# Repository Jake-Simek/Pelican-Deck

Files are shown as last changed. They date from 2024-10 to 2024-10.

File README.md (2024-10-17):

# Overview

This project is my first attempt at building a portable cyberdeck using a Raspberry Pi 4 and a Pelican 1150 case. It’s designed to be fully self-contained, with water-resistant ports, onboard battery power, and cooling fans. My main focus was to create a sleek, functional system for running various scripts and tasks, such as BadUSB attacks, while keeping everything compact and portable.
In the future, I plan to add assembly instructions to the wiki and more wiring diagrams and schematics.

Cyberdeck Build

---

## Features
- **7-inch display**: Built-in for portable use
- **Running Kali Linux**: Ideal for cybersecurity tasks
- **Active cooling system**: 1x 30mm fan and 2x 18mm fans provide airflow when the case is open
- **3 USB ports**: 2 internal, 1 external for peripherals
- **SD card reader**: Built-in for easy storage access
- **HDMI output**: External port for connecting to a larger display
- **USB-C charging**: Convenient power supply for both the Pi and the screen
- **Cat5 Ethernet port**: External network connection for wired access
- **Audio jack**: For headphones or external audio
- **Status LEDs**:
  - Charging indicator
  - Raspberry Pi on/off
  - Screen on/off
  - 3 additional customizable LEDs
- **Switch for screen power**: Automatically turns the screen off when the case is closed
- **Keyboard**: Integrated for ease of use
- **Storage compartments**: Holds SD cards and USB drives under the keyboard
- **Fully-contained battery**: Powers both the Raspberry Pi and screen for portable operation
- **Water-resistant design**: Sealed and protected when closed

---

## Known Issues
- **Overheating**: Cannot operate with the lid closed for extended periods due to heat buildup
- **No trackpad**: There's no way to control the cursor in the OS without an external mouse
- **Boot issue**: Raspberry Pi won’t boot from the SD card reader
- **Status LEDs**: The LEDs are too bright (can be fixed by using different resistors)
- **Charging inconvenience**: The keyboard has to be removed to access the charging port
- **Internal cable management**: Very poor, leading to a cluttered interior
- **Waterproofing**: The build does not maintain the Pelican case’s original waterproof rating
- **Glue used for assembly**: Insert/faceplate is fastened using glue, which could be improved
- **Charging limitations**: Only supports standard USB charging, not USB-C PD; USB-C port is not bi-directional (input only)

---

## Future Goals
- **Custom 18650 battery pack**: Build a battery pack to fit the case better, provide a longer runtime, and support USB-C PD input and output
- **Inductive charging**: Incorporate some form of wireless charging just because 
- **Slightly bigger case**: Upgrade to a larger case for better component fit and expansion
- **New cooling design**: Implement a thermoelectric cooling system to allow operation with the lid closed
- **Add a trackpad**: Include a built-in trackpad for easier navigation
- **Improved waterproofing**: Make the unit fully submersible when closed and water resistant when open 
- **Upgrade to Raspberry Pi 5**: Consider switching to a Raspberry Pi 5 for improved performance
- **Use fasteners instead of glue**: Replace glued components with screw fasteners for a cleaner, more durable assembly
- **Use SSD for booting**: Switch to an SSD for faster and more reliable booting
- **Design custom PCB**: Create a custom PCB for improved wire management and cleaner internal layout
- **More improvements to come**: This project is evolving, and additional upgrades are planned for future versions

---

## Parts List

#### Disclaimer
Some of the links may have changed, so the parts may not be *identical*. Everything looks the same on the listings, but these parts were all ordered over a year ago.

---

#### Case and External I/O

- **Pelican Case**: [Pelican 1150 Case](https://shorturl.at/xyr0k) or [alternative link](https://www.pelican.com/us/en/product/cases/protector/1150/)
- **Water-resistant Panel Mount I/O (sold by [Power Signal Data Connector Store](https://www.aliexpress.com/store/1102188024) on AliExpress)**:
  - [External HDMI Port](https://shorturl.at/CyrGC) or [alternative link](https://www.aliexpress.us/item/3256804676511038.html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)
  - [External USB Port](https://shorturl.at/Cf8bj) or [alternative link](https://www.aliexpress.us/item/3256805021108099.html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)
  - [External USB-C Port](https://shorturl.at/6hTVx) or [alternative link](https://www.aliexpress.us/item/3256804676644038.html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)
  - [External RJ45 Port](https://shorturl.at/9zwq1) or [alternative link](https://www.aliexpress.us/item/3256805248603359.html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)

  These can be ordered in any color and configuration, but I ordered mine in black with metal nuts. All connectors are ports, but soldering versions are available.

---

#### Display and Input

- **Display**: [7-inch 1024x600 HDMI Display](https://shorturl.at/NZxAf) or [alternative link](https://www.aliexpress.us/item/3256806868466798.html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)
- **Keyboard**: [7-inch Tablet Keyboard](https://a.co/d/doeQoq1) or [alternative link](https://www.amazon.com/dp/B088ZWT5N1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)
 – You can also find versions with a trackpad, but the keyboard base may need modification.
- - **3.5mm Audio Jack**: [Panel Mount 3.5mm Audio Jack (3-pin)](https://shorturl.at/4XXrT) or [alternative link](https://www.aliexpress.us/item/3256805998541350.html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)

---

#### Cooling and Switches

- **Fans**:
  - [30mm Fan (5V)](https://shorturl.at/P3yWi) or [alternative link](https://www.aliexpress.us/item/3256806120222119.html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)
  - [20mm Fan (5V Hydraulic Bearing)](https://a.co/d/7ztwXzH) or [alternative link](https://www.amazon.com/dp/B08MKVSKR6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)
- **Rocker Switches**: [Small Round 2-pin Rocker Switches](https://shorturl.at/hRt7r) or [alternative link](https://www.aliexpress.us/item/3256807356199141.html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)
- **Lid Switch**: [Refrigerator Door Light Switch (Normally Closed)](https://a.co/d/ivMNV4H) or [alternative link](https://shorturl.at/g9zLX)

---

#### Internal Components

- **Internal USB Ports**: [USB to USB 3.0 Dual Panel Mount](https://a.co/d/hqzMyTw) or [alternative link](https://www.amazon.com/dp/B09QQJJML1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)
- **SD Card Extender**: [Micro SD to SD Card Extender](https://shorturl.at/vaQC8) or [alternative link](https://www.aliexpress.us/item/3256803938544773.html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)
  > Note: For some reason, the Pi won't boot from an SD card plugged into this. I'm currently using it with a USB to Micro-USB adapter for reading SD cards, but it works intermittently. You may want to find an alternative.
- **Brass Standoffs**: [Brass Standoffs](https://shorturl.at/BhvH3) or [alternative link](https://www.aliexpress.us/item/2251832748907515.html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) – Any small standoff that fits the Pi’s holes should work fine. I inserted mine into the 3D printed part using a soldering iron. 

---

#### LEDs and Power

- **LEDs and Resistors**:
  - [5mm LEDs](https://shorturl.at/MhEKz) or [alternative link](https://www.aliexpress.us/item/3256805522196114.html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) – Any standard 5mm LED will work; mine were pulled from a DIY Pi kit. 
  - [390 Ohm Resistors](https://shorturl.at/njeu3) or [alternative link](https://www.aliexpress.us/item/3256804747550699.html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) – Used for the LEDs. You may want to use a higher resistance as these are quite bright. 
- **Diode**: [3A Diode (supports 5V)](https://a.co/d/aqU21aW) or [alternative link](https://www.amazon.com/dp/B0D4QNTT4V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)
 – This is used to prevent the charging LED from being powered by the battery bank, so it only turns on during charging. This setup prevents the USB-C port from being used as a power source, as noted in the issues section. 
---

#### Cables and Wiring

- **Cables**:
  - [Micro HDMI to HDMI](https://shorturl.at/lDclC) or [alternative link](https://www.aliexpress.us/item/3256802014452724.html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)
  - [Micro HDMI to Mini HDMI](https://a.co/d/1WwkHYU) or [alternative link](https://www.amazon.com/dp/B08BFZFT7R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)
  - [USB A to USB A](https://shorturl.at/Ay4hM) or [alternative link](https://www.aliexpress.us/item/3256806526879520.html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) – I made my own, but this should work. 
  - [RJ45 Male to RJ45 Male](https://shorturl.at/zojFO) or [alternative link](https://www.aliexpress.us/item/2251832635496878.html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)
 – I made my own, but this should work.
- **Wiring and Heatshrink**: I used spare 22AWG wire and heatshrink, but you can find similar materials [here](https://shorturl.at/3O9jX) and [here](https://shorturl.at/ypX5P) for the USB-C and micro USB connections (Pi, screen, and charging). You may need some non-USB-C PD cables and ends to solder up. 
---

#### 3D Printed Parts

- **3D Printed Components**: All parts are printed with [**Polymaker PETG**](https://us.polymaker.com/products/polylite-petg), but any standard filament should work.

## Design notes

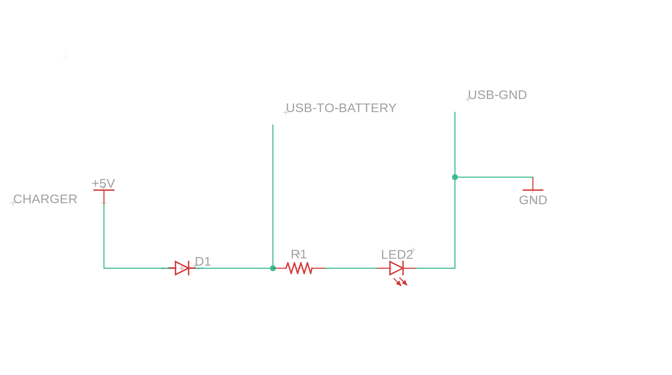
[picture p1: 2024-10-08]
Charging LED Schematic.png

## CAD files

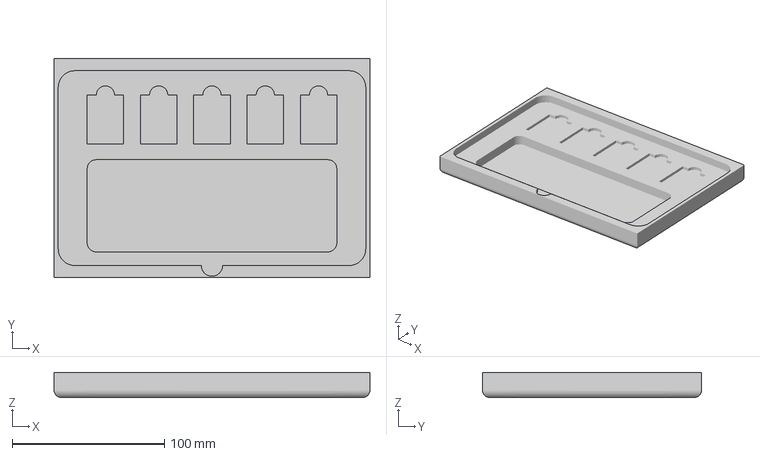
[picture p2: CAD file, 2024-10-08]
Keyboard Base.3mf
207.6 x 144.1 x 16.5 mm

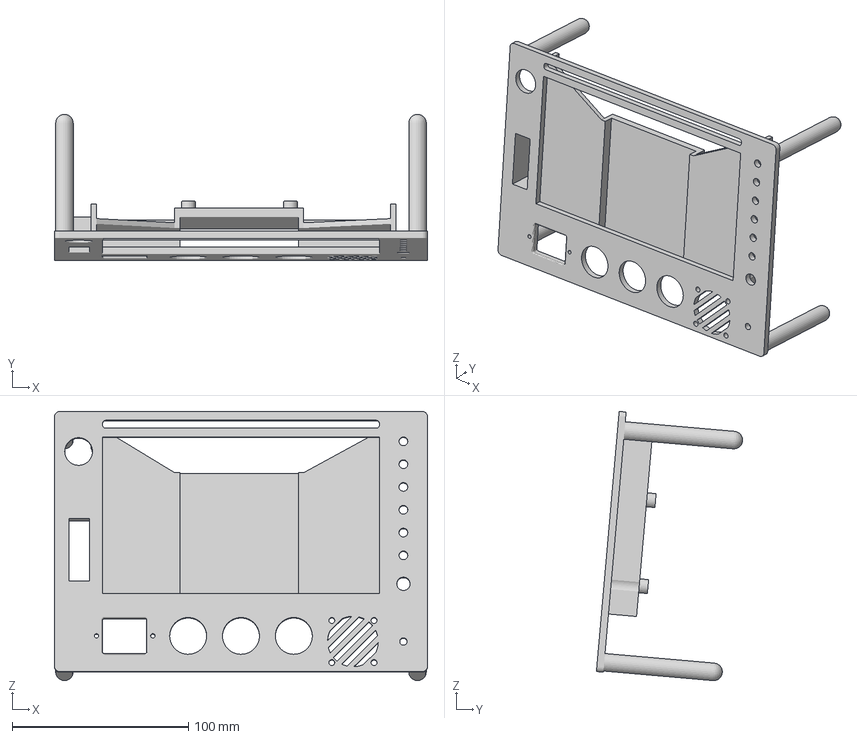
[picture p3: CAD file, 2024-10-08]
Frame.3mf
211.8 x 83.0 x 152.8 mm

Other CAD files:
Frame.stl
Keyboard Base.stl

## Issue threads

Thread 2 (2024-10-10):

All Aliexpress links dud

Bazmundi, 2024-10-10:
Title, all Aliexpress links for connectors are dead.  Probably just needs the [store link](https://www.aliexpress.com/store/1102181980)?

Jake-Simek, 2024-10-10:
Sorry about that, I will get that fixed as soon as possible.

Closed 2024-10-11.

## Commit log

2024-10-08 printed parts
    [Frame.3mf, Frame.stl, Keyboard Base.3mf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]
2024-10-08 added cad files
